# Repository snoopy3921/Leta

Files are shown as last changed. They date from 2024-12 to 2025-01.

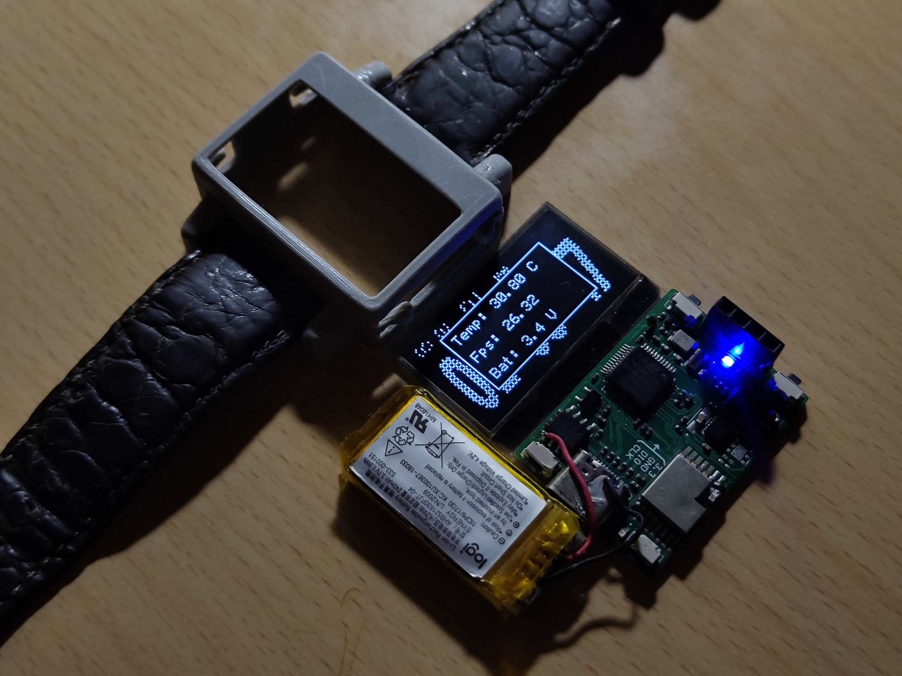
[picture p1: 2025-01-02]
assets/assembled.jpg

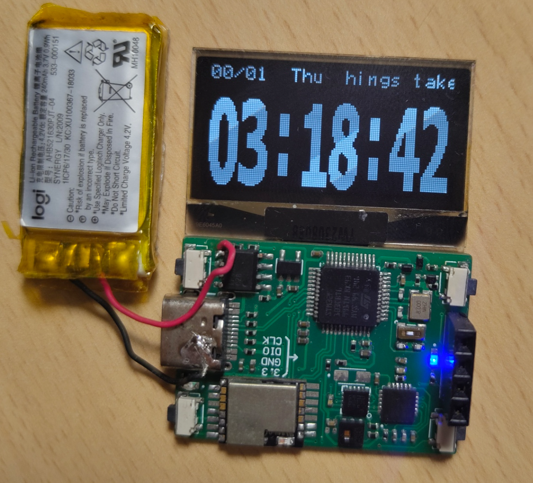
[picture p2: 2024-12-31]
assets/assembled.png

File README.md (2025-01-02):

# Leta
```The name:``` Leta is summer in russia. It is the time that i started to make my own wrist watch.

<figure>
  <img
  src="assets/P1210208.JPG">
  <figcaption align=center>Oled wrist watch using Stm32f1 with mini RTOS and Monochrome GUI</figcaption>
</figure>

# Demo
<div align="center">
    <video src="https://github.com/user-attachments/assets/c9f8b56e-a367-4709-93c1-a5930ff01f5d" alt="Leta demo" />
</div>

Link youtube:

https://www.youtube.com/watch?v=F7zo0RkRJ88

# Schematic

<figure>
  <img
  src="assets/Schema.png">
</figure>

+ Microcontroller: Stm32f103xx, 128 kB ROM, 20 kB RAM. Build-int RTC.
+ IMU: MPU6050, HCM5883L.
+ Temp and humid: HTU21D.
+ Bluetooth: RF-BM-4044B4(RF-Star).
+ Display: SH1106 oled 1.3" 128x64.
+ Power: TP4056 charger IC, regulator 3.3V AP2112.

# PCB
<figure>
  <img
  src="assets/Pcb.png">
</figure>

+ 2 layers
+ USB interface
+ 1 port SWD interface
+ 4 buttons

<figure>
  <img
  src="assets/3d_view.png">
</figure>

<figure>
  <img
  src="assets/3_pcb.png">
</figure>

<figure>
  <img
  src="assets/assembled.jpg">
</figure>

# Enclosure

<figure>
  <img
  src="assets/case.gif">
</figure>

# Program layers

<figure>
  <img
  src="assets/program_layer.png">
</figure>

## AK-mOS
This project uses a mini RTOS (AK-mOS) which written by me for AK-base-kit (ARM cortex M3). 

The kit you can check out here:

https://github.com/epcbtech/ak-base-kit-stm32l151

The mini RTOS has following features:
+ Preemptive scheduling
+ Round-robin scheduling
+ Inner tasks communiation
+ Software timer

More detail about it: 

https://github.com/snoopy3921/AK-mOS---The-simple-RTOS-on-AK-base-kit

This mini RTOS was created for learning purpose with context switch based on freeRTOS.

Im hoping this OS can be used more to test stability.

## Oled GUI
To control oled display with rich animating. I wrote the library to increase experience on UI.

The UI has some widget like:
+ Switch
+ Label text
+ Check box
+ Bitmap
+ Indicator
+ Pop-up notify
+ Slider

Animating can do these things to widgets:
+ Fading
+ Moving
+ Resizing

Check out here is more detail about my GUI:

https://github.com/snoopy3921/Monochrome-Oled-GUI

# References
These links below are materials which helped me a lot when bulding my project:

+ https://github.com/ZeekiChen/iWatch-v2.0
+ https://github.com/lvgl/lvgl
+ https://github.com/Sheep118/WouoUI-PageVersion
+ https://github.com/epcbtech/ak-base-kit-stm32l151
+ https://github.com/FreeRTOS/FreeRTOS-Kernel

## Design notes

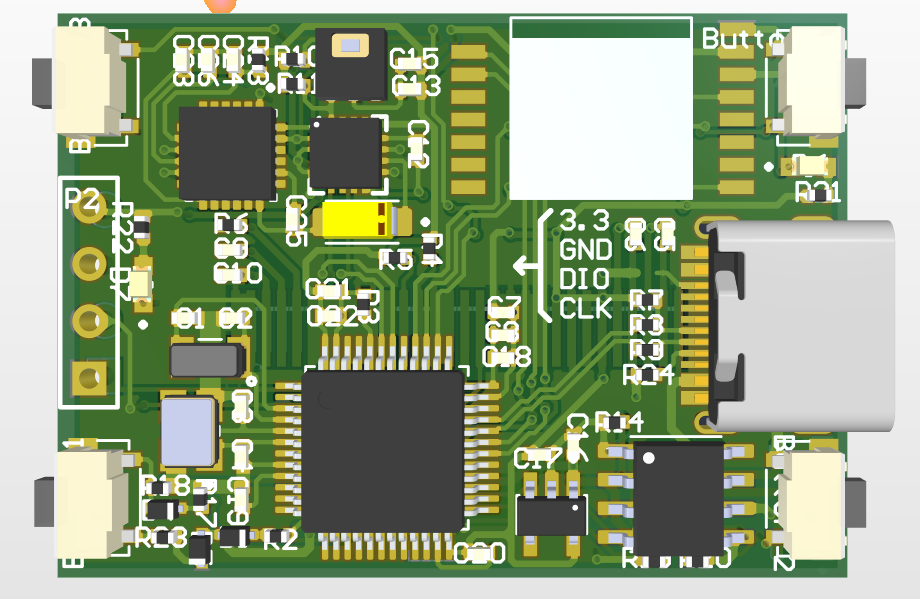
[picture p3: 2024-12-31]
assets/3d_view.png

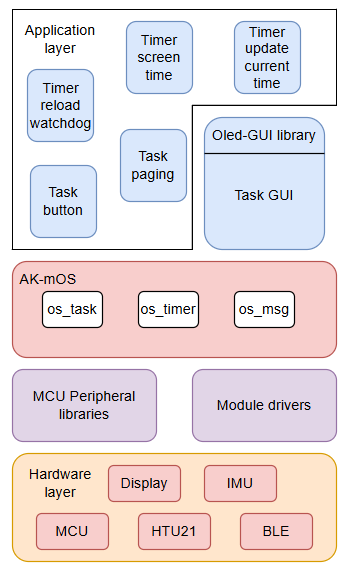
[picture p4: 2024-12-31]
assets/program_layer.png

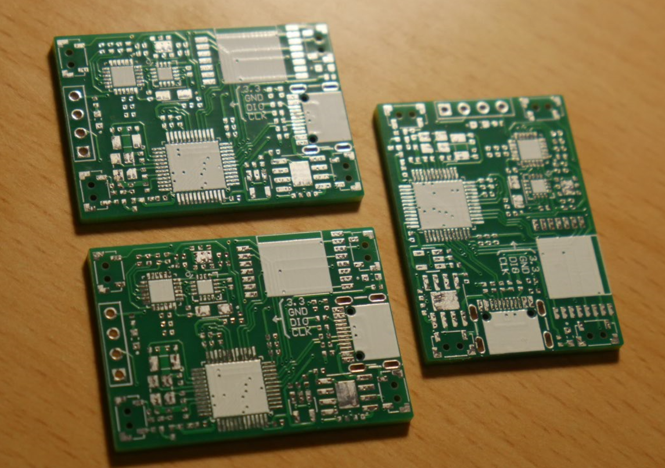
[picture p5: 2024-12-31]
assets/3_pcb.png

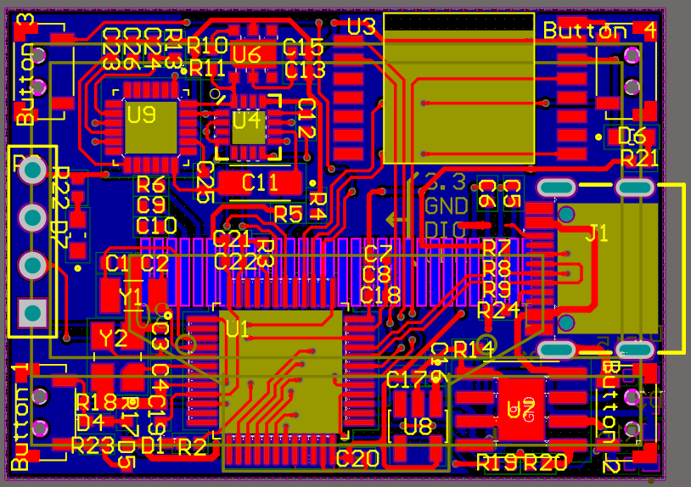
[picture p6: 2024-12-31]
assets/Pcb.png

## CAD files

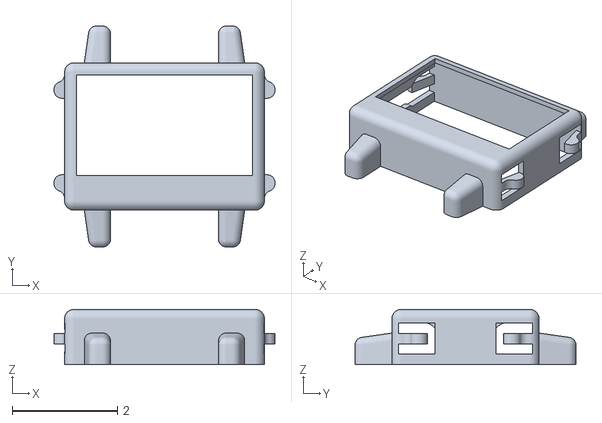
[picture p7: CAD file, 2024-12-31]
hardware/Watch_Case.stl
4.20 x 4.20 x 1.05

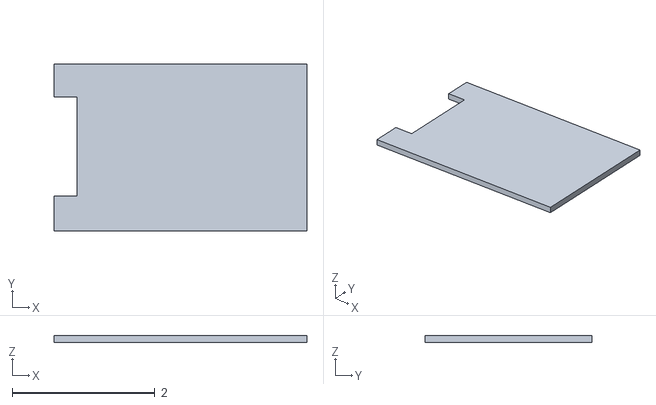
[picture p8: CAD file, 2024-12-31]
hardware/Watch_Case_Cover.stl
3.54 x 2.34 x 0.1

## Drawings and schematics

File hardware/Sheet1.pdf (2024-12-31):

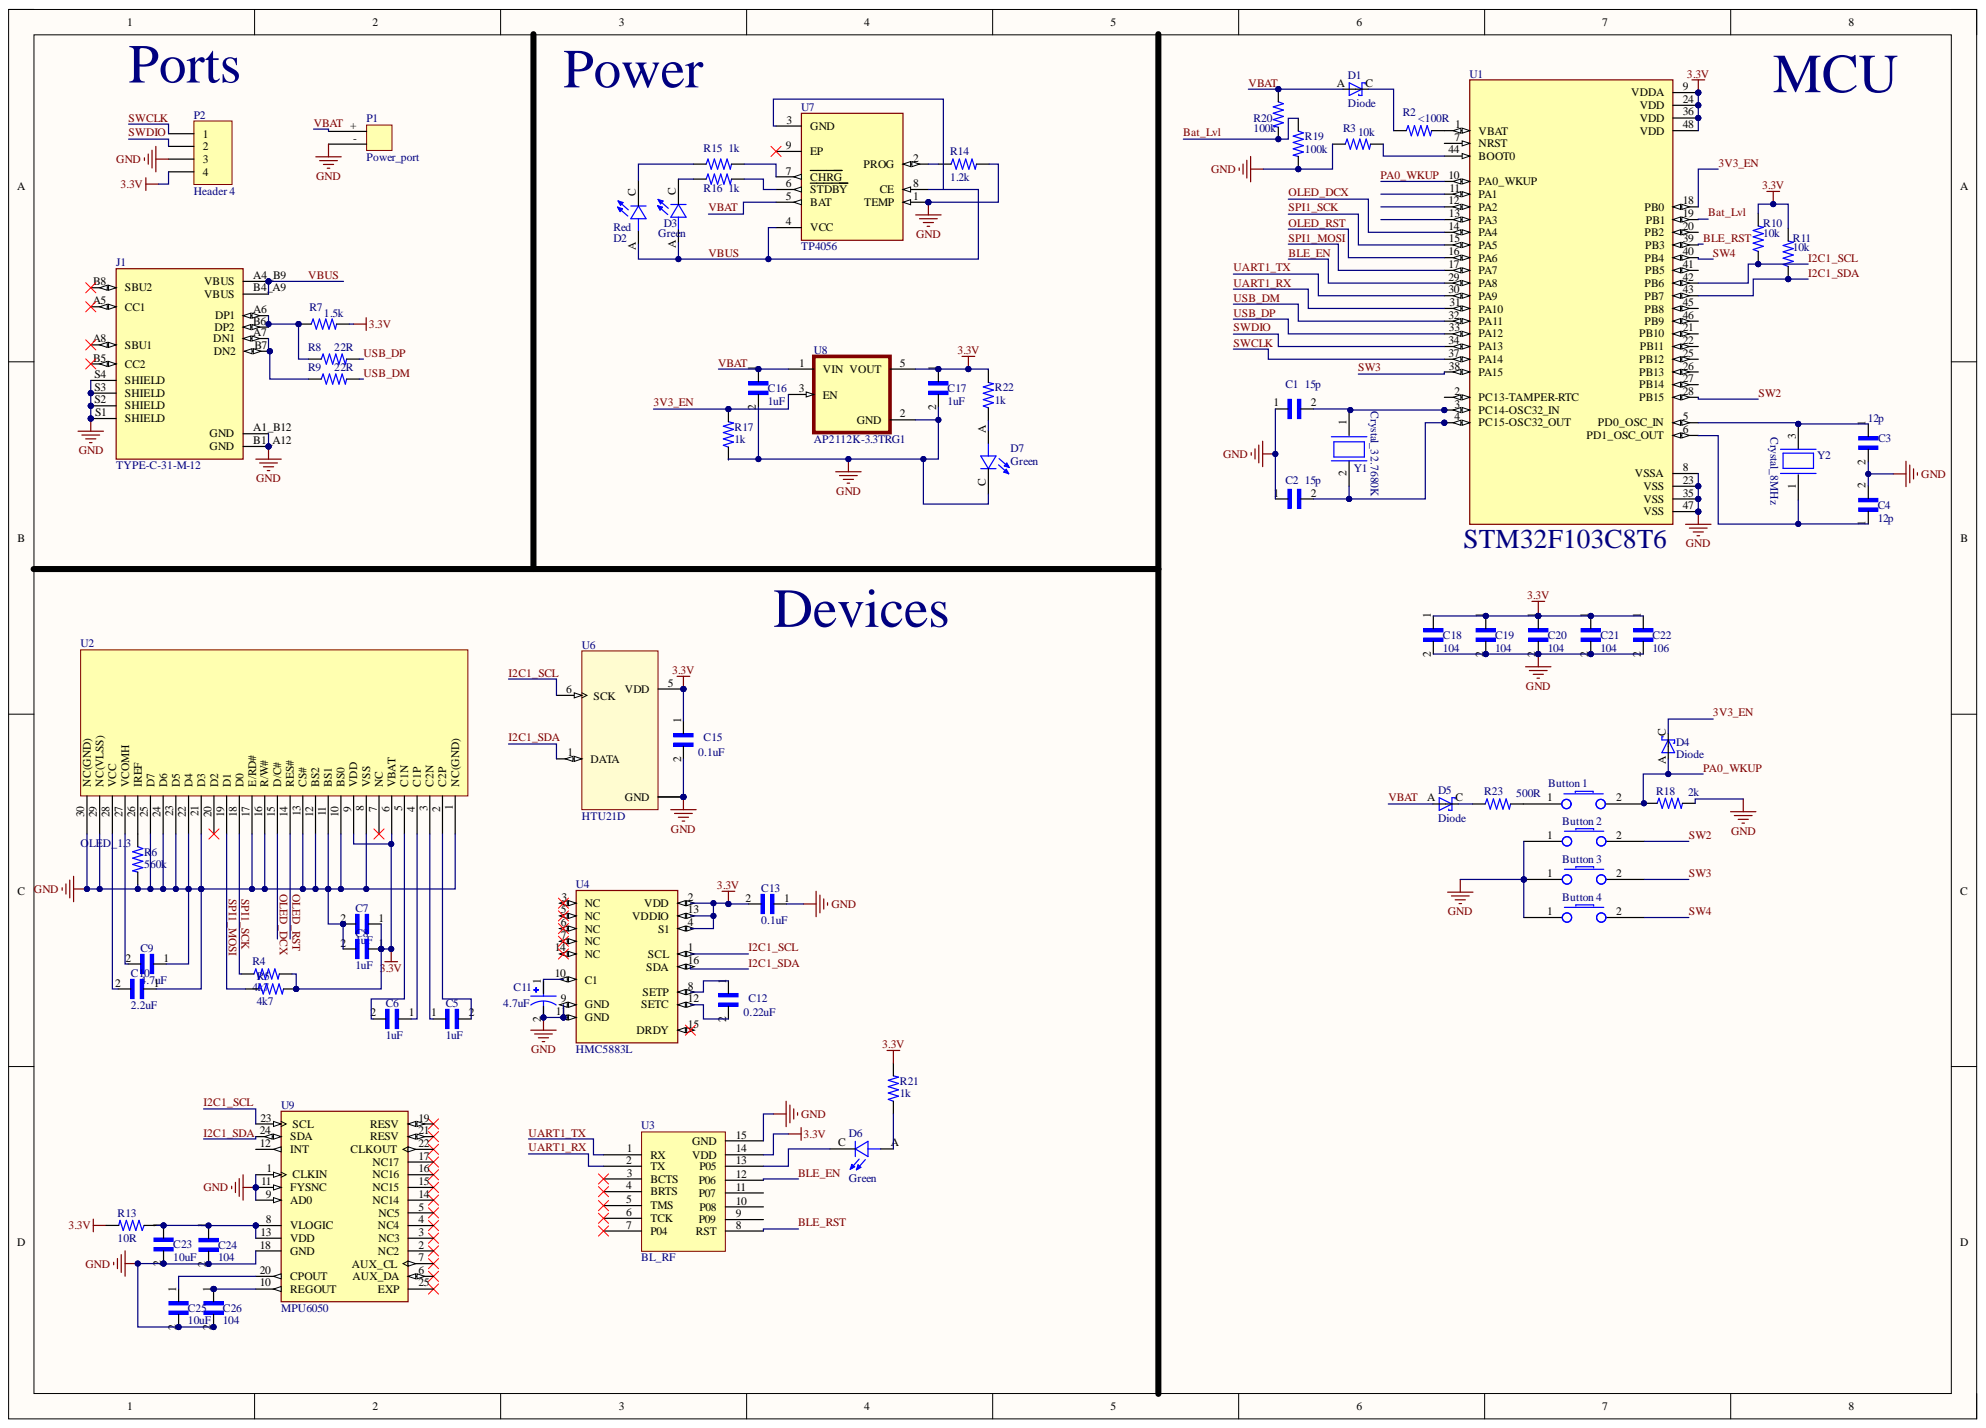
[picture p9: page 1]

OLED_RST | PA4 14
SPI1_MOSI | PA5 15

NC(GND) 1 C2P 2 C2N 3 C1P 4 C1N 5 VBAT 6 NC 7 VSS 8 VDD 9 BS0 10 BS1 11 BS2 12 CS# 13 RES# 14 D/C# 15 R/W# 16 E/RD# 17 D0 18 D1 19 D2 20 D3 21 D4 22 D5 23 D6 24 D7 25 IREF 26 VCOMH 27 VCC 28 NC(VLSS) 29 NC(GND) 30 U2

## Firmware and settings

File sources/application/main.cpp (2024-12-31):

#include "main.h"

#include "gui.h"
#include "gui_port.h"
#include "math.h"
#include "cmath"
const uint8_t low_batt [] = {
	0x00, 0x00, 0x00, 0x00, 0x00, 0x00, 0x00, 0x00, 0x00, 0x00, 0x00, 0x00, 0x00, 0x00, 0x00, 0x00, 
	0x00, 0x00, 0x00, 0x00, 0x00, 0x00, 0x00, 0x00, 0x00, 0x00, 0x00, 0x00, 0x00, 0x00, 0x00, 0x00, 
	0x00, 0x00, 0x00, 0x00, 0x00, 0x00, 0x00, 0x00, 0x00, 0x00, 0x00, 0x00, 0x00, 0x00, 0x00, 0x00, 
	0x00, 0x00, 0x00, 0x00, 0x00, 0x80, 0xe0, 0xe0, 0xf0, 0xf0, 0xf0, 0xf0, 0xf0, 0xf0, 0xf0, 0xf0, 
	0xf0, 0xf0, 0xf0, 0xf0, 0xf0, 0xf0, 0xf0, 0xf0, 0xf0, 0xf0, 0xf0, 0xf0, 0xf0, 0xf0, 0xf0, 0xf0, 
	0xf0, 0xf0, 0xf0, 0xf0, 0xf0, 0xf0, 0xf0, 0xf0, 0xf0, 0xf0, 0xf0, 0xf0, 0xe0, 0xe0, 0x80, 0x00, 
	0x00, 0x00, 0x00, 0x00, 0x00, 0x00, 0x00, 0xff, 0xff, 0xff, 0xff, 0x00, 0x00, 0xff, 0xff, 0x00, 
	0x00, 0xff, 0xff, 0xff, 0xff, 0xff, 0xff, 0xff, 0xff, 0xff, 0xff, 0xff, 0xff, 0xff, 0xff, 0xff, 
	0xff, 0xff, 0xff, 0xff, 0xff, 0xff, 0xff, 0xff, 0xff, 0xff, 0xff, 0xff, 0xff, 0xff, 0xff, 0xff, 
	0xff, 0xf0, 0xf0, 0xf0, 0x00, 0x00, 0x00, 0x00, 0x00, 0xff, 0xff, 0xff, 0xff, 0x00, 0x00, 0xff, 
	0xff, 0x00, 0x00, 0xff, 0xff, 0xff, 0xff, 0xff, 0xff, 0xff, 0xff, 0xff, 0xff, 0xff, 0xff, 0xff, 
	0xff, 0xff, 0xff, 0xff, 0xff, 0xff, 0xff, 0xff, 0xff, 0xff, 0xff, 0xff, 0xff, 0xff, 0xff, 0xff, 
	0xff, 0xff, 0xff, 0x3f, 0x3f, 0x3f, 0x00, 0x00, 0x00, 0x00, 0x00, 0x07, 0x1f, 0x1f, 0x3f, 0x3c, 
	0x3c, 0x3f, 0x3f, 0x3c, 0x3c, 0x3f, 0x3f, 0x3f, 0x3f, 0x3f, 0x3f, 0x3f, 0x3f, 0x3f, 0x3f, 0x3f, 
	0x3f, 0x3f, 0x3f, 0x3f, 0x3f, 0x3f, 0x3f, 0x3f, 0x3f, 0x3f, 0x3f, 0x3f, 0x3f, 0x3f, 0x3f, 0x3f, 
	0x3f, 0x3f, 0x1f, 0x1f, 0x07, 0x00, 0x00, 0x00, 0x00, 0x00, 0x00, 0x00, 0x00, 0x00, 0x00, 0x00, 
	0x00, 0x00, 0x00, 0x00, 0x00, 0x00, 0x00, 0x00, 0x00, 0x00, 0x00, 0x00, 0x00, 0x00, 0x00, 0x00, 
	0x00, 0x00, 0x00, 0x00, 0x00, 0x00, 0x00, 0x00, 0x00, 0x00, 0x00, 0x00, 0x00, 0x00, 0x00, 0x00, 
	0x00, 0x00, 0x00, 0x00, 0x00, 0x00, 0x00, 0x00, 0x00, 0x00, 0x00, 0x00, 0x00, 0x00, 0x00, 0x00, 
	0x00, 0x00, 0x00, 0x00, 0x00, 0x00, 0x00, 0x00, 0x00, 0x00, 0x00, 0x00, 0x00, 0x00, 0x00, 0x00, 
	0x00, 0x00, 0x00, 0x00, 0x00, 0x00, 0x00, 0x00, 0x00, 0x00, 0x00, 0x00, 0x00, 0x00, 0x00, 0x00, 
	0x00, 0x00, 0x00, 0x00, 0x00, 0x00, 0x00, 0x00, 0x00, 0x00, 0x00, 0x00, 0x00, 0x00
};

void task_gui(void *p_arg)
{   
    while (1)
    {
        gui_run();
    }
}

void task_page_mng(void *p_arg)
{
    msg_t * msg;
    gui_page_init();  
    while (1)
    {
        msg = os_task_wait_for_msg(0);
        gui_page_run(msg);
        if(msg != NULL) os_msg_free(msg);
    }
}

RTCSTM32 watch_time;
RTCDateTime watch_time_now;
watch_config config;
MPU6050_t mpu;
float bat_voltage;
float watch_temp;

os_timer_t *p_timer_update_watch_time;
os_timer_t *p_timer_reload_watchdog;
os_timer_t *p_timer_countdown_screen_time;

static void update_watch_time(void)
{
    watch_time_now = watch_time.getDateTime();
}

static void reload_watchdog(void)
{
    watchdog_hw_reload();
    watch_temp = adc_get_temp();
    bat_voltage = adc_get_bat_voltage();
    if(bat_voltage < (float)3.35) power_pin_off();
    
}

void countdown_screen_time(void)
{
    config_data_write(&config);
    power_pin_off();
}






int main()
{
    power_pin_init();
    power_pin_on();
    /* button init */
    button_init(&btn_up_left,	10,	BUTTON_HW_PRESSED_LOW,	btn_ul_init,	btn_ul_read,	btn_up_left_callback);
    button_init(&btn_up_right,	10,	BUTTON_HW_PRESSED_LOW,	btn_ur_init,	btn_ur_read,	btn_up_right_callback);
	button_init(&btn_down_left,	10,	BUTTON_HW_PRESSED_LOW,	btn_dl_init,	btn_dl_read,	btn_down_left_callback);
    button_init(&btn_down_right,	10,	BUTTON_HW_PRESSED_HIGH,	btn_dr_init,	btn_dr_read,	btn_down_right_callback);

	button_enable(&btn_up_left);
	button_enable(&btn_up_right);
	button_enable(&btn_down_left);
    button_enable(&btn_down_right);

    config_data_init();
    config_data_read(&config);

    adc_hw_init();
    i2c_hw_init();
    watchdog_hw_init();

    MPU6050_Init();

    watch_time.init();




    gui_initialize();

    bat_voltage = adc_get_bat_voltage();    
    if( bat_voltage < (float)3.35 )
    {
        gui_clear_buff();
        gui_window_draw_bmp(&window_screen_size, 40, 10, 50, 50, low_batt, DRAW_STATE_ON);
        gui_window_draw_str(&window_screen_size, 22, 10, "Please charge!", DRAW_STATE_ON);
        gui_refresh();
        for(int i = 0; i < 10000000; i++);
        power_pin_off();
    }


    oled_set_brightness(config.screen_brightness);
    oled_invert(config.screen_inverse);



    os_init();
    os_task_create_list((task_t*)app_task_table, TASK_EOT_ID);

    /* Timer creation */
    p_timer_update_watch_time = os_timer_create(TIMER_UPDATE_WATCH_TIME_ID, 0, update_watch_time, 0, 59000, TIMER_PERIODIC); /* Update every 59s ))))*/
    p_timer_reload_watchdog = os_timer_create(TIMER_RELOAD_WATCH_DOG, 0, reload_watchdog, 0, 500, TIMER_PERIODIC); /* Update every 500ms*/
    p_timer_countdown_screen_time = os_timer_create(TIMER_COUNT_DOWN_SCREEN_TIME, 0, countdown_screen_time, 0, config.screen_time * 1000, TIMER_ONE_SHOT); 
    
    os_timer_start(p_timer_update_watch_time, 0);
    os_timer_start(p_timer_reload_watchdog, 0);
    os_timer_start(p_timer_countdown_screen_time, 0);
    /* Timer creation end*/

    os_run();


    while(1)
    {	

    }
}

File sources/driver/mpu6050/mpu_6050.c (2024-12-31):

/*
 * mpu6050.c
 *
 *  Created on: Nov 13, 2019
 *      Author: Bulanov Konstantin
 *
 *  Contact information
 *  -------------------
 *
 * e-mail   :  leech001@gmail.com
 */

/*
 * |---------------------------------------------------------------------------------
 * | Copyright (C) Bulanov Konstantin,2021
 * |
 * | This program is free software: you can redistribute it and/or modify
 * | it under the terms of the GNU General Public License as published by
 * | the Free Software Foundation, either version 3 of the License, or
 * | any later version.
 * |
 * | This program is distributed in the hope that it will be useful,
 * | but WITHOUT ANY WARRANTY; without even the implied warranty of
 * | MERCHANTABILITY or FITNESS FOR A PARTICULAR PURPOSE.  See the
 * | GNU General Public License for more details.
 * |
 * | You should have received a copy of the GNU General Public License
 * | along with this program.  If not, see <http://www.gnu.org/licenses/>.
 * |
 * | Kalman filter algorithm used from https://github.com/TKJElectronics/KalmanFilter
 * |---------------------------------------------------------------------------------
 */

#include <math.h>
#include "mpu_6050.h"
#include "io_cfg.h"
#include "os_task.h"

#define RAD_TO_DEG 57.295779513082320876798154814105

#define WHO_AM_I_REG 			0x75
#define CONFIG 						0x1A
#define INT_ENABLE 				0x38
#define MOT_THR 					0x1F
#define MOT_DUR 					0x69
#define INT_PIN_CFG 			0x37
#define PWR_MGMT_1_REG 		0x6B
#define PWR_MGMT_2_REG 		0x6C
#define SMPLRT_DIV_REG 		0x19
#define ACCEL_CONFIG_REG 	0x1C
#define ACCEL_XOUT_H_REG 	0x3B
#define TEMP_OUT_H_REG 		0x41
#define GYRO_CONFIG_REG 	0x1B
#define GYRO_XOUT_H_REG 	0x43

// Setup MPU6050
#define MPU6050_ADDR 0xD0
const uint16_t i2c_timeout = 100;
const double Accel_Z_corrector = 14418.0;
uint32_t timer;
Kalman_t KalmanX = {
    .Q_angle = 0.001f,
    .Q_bias = 0.003f,
    .R_measure = 0.03f
};

Kalman_t KalmanY = {
    .Q_angle = 0.001f,
    .Q_bias = 0.003f,
    .R_measure = 0.03f,
};


bool MPU6050_Init(void)
{
	if(i2c_hw_read(MPU6050_ADDR, WHO_AM_I_REG) == 0x68)
	{
		i2c_hw_write(MPU6050_ADDR, PWR_MGMT_1_REG, 0x00);			
		i2c_hw_write(MPU6050_ADDR, SMPLRT_DIV_REG, 0x07);		//Data rate 1kHz where Gyroscope Output Rate = 8kHz
		i2c_hw_write(MPU6050_ADDR, GYRO_CONFIG_REG, 0x00);		//Full scale range
		i2c_hw_write(MPU6050_ADDR, ACCEL_CONFIG_REG, 0x00);	    //Full scale range
		return true;
	}
	else return false;
}
void MPU6050_LowPwrAccelOnly(void)
{
	uint8_t temp = i2c_hw_read(MPU6050_ADDR, PWR_MGMT_1_REG);
	i2c_hw_write(MPU6050_ADDR, PWR_MGMT_1_REG, temp & ~0x30);	//Clear Sleep and cycle
	i2c_hw_write(MPU6050_ADDR, PWR_MGMT_1_REG, temp |  0x00);	//Make sure MPU is running
	
	
  temp = i2c_hw_read(MPU6050_ADDR, PWR_MGMT_2_REG);
  i2c_hw_write(MPU6050_ADDR, PWR_MGMT_2_REG, temp & ~0x38); // Clear standby XA, YA, and ZA bits [3:5]
  i2c_hw_write(MPU6050_ADDR, PWR_MGMT_2_REG, temp |  0x00); // Set XA, YA, and ZA bits [3:5] to zero to make sure accelerometer is running
	
	temp = i2c_hw_read(MPU6050_ADDR, CONFIG);
  i2c_hw_write(MPU6050_ADDR, CONFIG, temp & ~0x07); // Clear Filter [2:0]
  i2c_hw_write(MPU6050_ADDR, CONFIG, temp |  0x00); // Set filter DLPF_CFG = 0
	
// 	temp = i2c_hw_read(MPU6050_ADDR, INT_ENABLE);
//   i2c_hw_write(MPU6050_ADDR, INT_ENABLE, temp & ~0xFF); // Clear all interrupts
//   i2c_hw_write(MPU6050_ADDR, INT_ENABLE, temp |  0x40); // MOT_EN
	
// 	i2c_hw_write(MPU6050_ADDR, MOT_THR, 0x80); // Set motion detection to 0.256 g; LSB = 2 mg
//   i2c_hw_write(MPU6050_ADDR, MOT_DUR, 0x01); // Set motion detect duration to 1  ms; LSB is 1 ms @ 1 kHz rate
	
	
	temp = i2c_hw_read(MPU6050_ADDR, ACCEL_CONFIG_REG);
  i2c_hw_write(MPU6050_ADDR, ACCEL_CONFIG_REG, temp & ~0x07); // Clear high-pass filter bits [2:0]
  i2c_hw_write(MPU6050_ADDR, ACCEL_CONFIG_REG, temp |  0x07); // Set ACCEL_HPF to 7; hold the initial accleration value as a referance
	
	temp = i2c_hw_read(MPU6050_ADDR, PWR_MGMT_2_REG);
  i2c_hw_write(MPU6050_ADDR, PWR_MGMT_2_REG, temp & ~0xC7); // Clear standby XA, YA, and ZA bits [3:5] and LP_WAKE_CTRL bits [6:7]
  i2c_hw_write(MPU6050_ADDR, PWR_MGMT_2_REG, temp |  0x47); // Set wakeup frequency to 5 Hz, and disable XG, YG, and ZG gyros (bits [0:2])  
	
	temp = i2c_hw_read(MPU6050_ADDR, PWR_MGMT_1_REG);
  i2c_hw_write(MPU6050_ADDR, PWR_MGMT_1_REG, temp & ~0x20); // Clear sleep and cycle bit 5
  i2c_hw_write(MPU6050_ADDR, PWR_MGMT_1_REG, temp |  0x20); // Set cycle bit 5 to begin low power accelerometer motion interrupts
	
	//i2c_hw_write(MPU6050_ADDR, INT_PIN_CFG, 0x80); // Clear sleep and cycle bit 5
}
void MPU6050_Read_Accel(MPU6050_t * DataStruct)
{
	uint8_t Rec_Data[6];
	i2c_hw_read_multi(MPU6050_ADDR, ACCEL_XOUT_H_REG, Rec_Data, 6);
  DataStruct->Accel_X_RAW = (int16_t)(Rec_Data[0] << 8 | Rec_Data[1]);
  DataStruct->Accel_Y_RAW = (int16_t)(Rec_Data[2] << 8 | Rec_Data[3]);
  DataStruct->Accel_Z_RAW = (int16_t)(Rec_Data[4] << 8 | Rec_Data[5]);
  /*** convert the RAW values into acceleration in 'g'
       we have to divide according to the Full scale value set in FS_SEL
       I have configured FS_SEL = 0. So I am dividing by 16384.0
       for more details check ACCEL_CONFIG Register              ****/

  DataStruct->Ax = DataStruct->Accel_X_RAW / 16384.0;
  DataStruct->Ay = DataStruct->Accel_Y_RAW / 16384.0;
  DataStruct->Az = DataStruct->Accel_Z_RAW / Accel_Z_corrector;
}
void MPU6050_Read_Gyro(MPU6050_t * DataStruct)
{
	uint8_t Rec_Data[6];
	i2c_hw_read_multi(MPU6050_ADDR, GYRO_XOUT_H_REG, Rec_Data, 6);
  DataStruct->Gyro_X_RAW = (int16_t)(Rec_Data[0] << 8 | Rec_Data[1]);
  DataStruct->Gyro_Y_RAW = (int16_t)(Rec_Data[2] << 8 | Rec_Data[3]);
  DataStruct->Gyro_Z_RAW = (int16_t)(Rec_Data[4] << 8 | Rec_Data[5]);
  /*** convert the RAW values into dps (?/s)
       we have to divide according to the Full scale value set in FS_SEL
       I have configured FS_SEL = 0. So I am dividing by 131.0
       for more details check GYRO_CONFIG Register              ****/

  DataStruct->Gx = (DataStruct->Gyro_X_RAW / 131.0) ;
  DataStruct->Gy = (DataStruct->Gyro_Y_RAW / 131.0) ;
  DataStruct->Gz = -1 * DataStruct->Gyro_Z_RAW / 131.0;
}
void MPU6050_Read_Temp(MPU6050_t *DataStruct)
{
    uint8_t Rec_Data[2];
    int16_t temp;
    // Read 2 BYTES of data starting from TEMP_OUT_H_REG register
		i2c_hw_read_multi(MPU6050_ADDR, TEMP_OUT_H_REG, Rec_Data, 2);

    temp = (int16_t)(Rec_Data[0] << 8 | Rec_Data[1]);
    DataStruct->Temperature = (float)((int16_t)temp / (float)340.0 + (float)36.53);
}
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
